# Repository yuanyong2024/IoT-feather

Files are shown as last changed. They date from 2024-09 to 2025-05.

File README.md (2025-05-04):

### This is a BG95 EVB in adafruit feather form-factor.
### It can be developed by quecpython, similar to circuit python
QQ截图20250504175747
QQ截图20250504175759

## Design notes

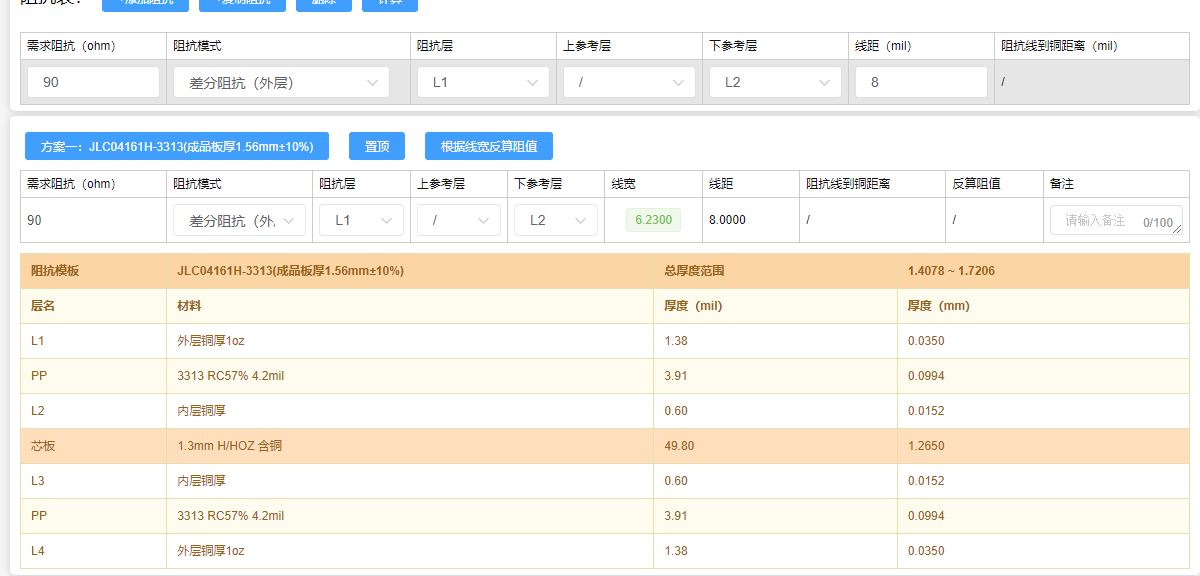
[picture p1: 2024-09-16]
hw/v0.2/90ohm_impedance_top.png

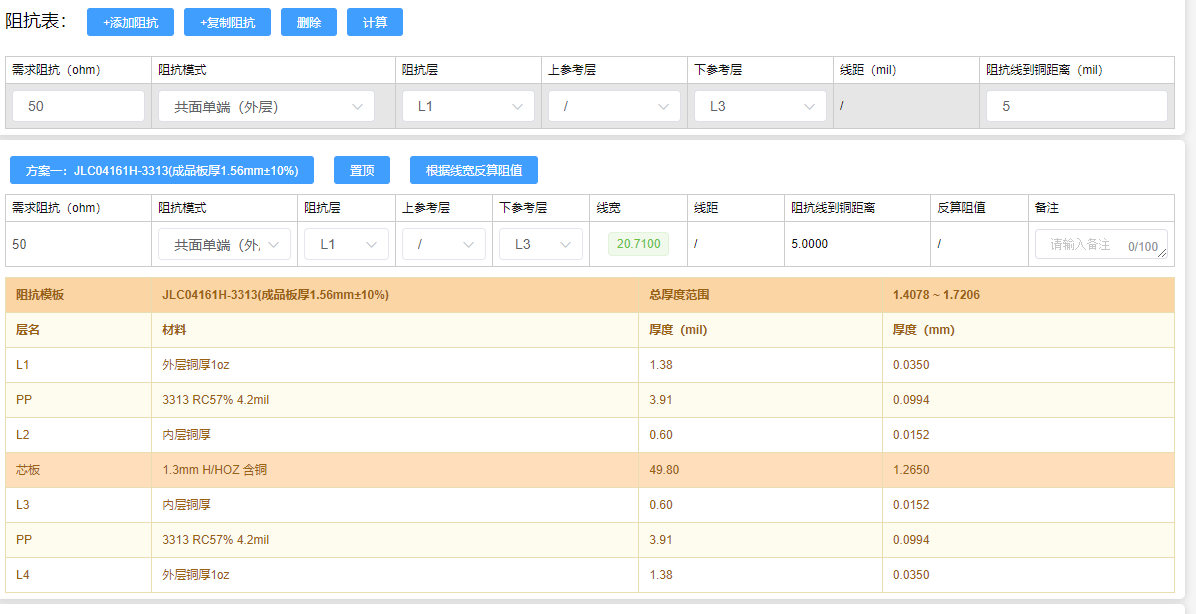
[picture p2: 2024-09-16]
hw/v0.2/50ohm_impedance.png

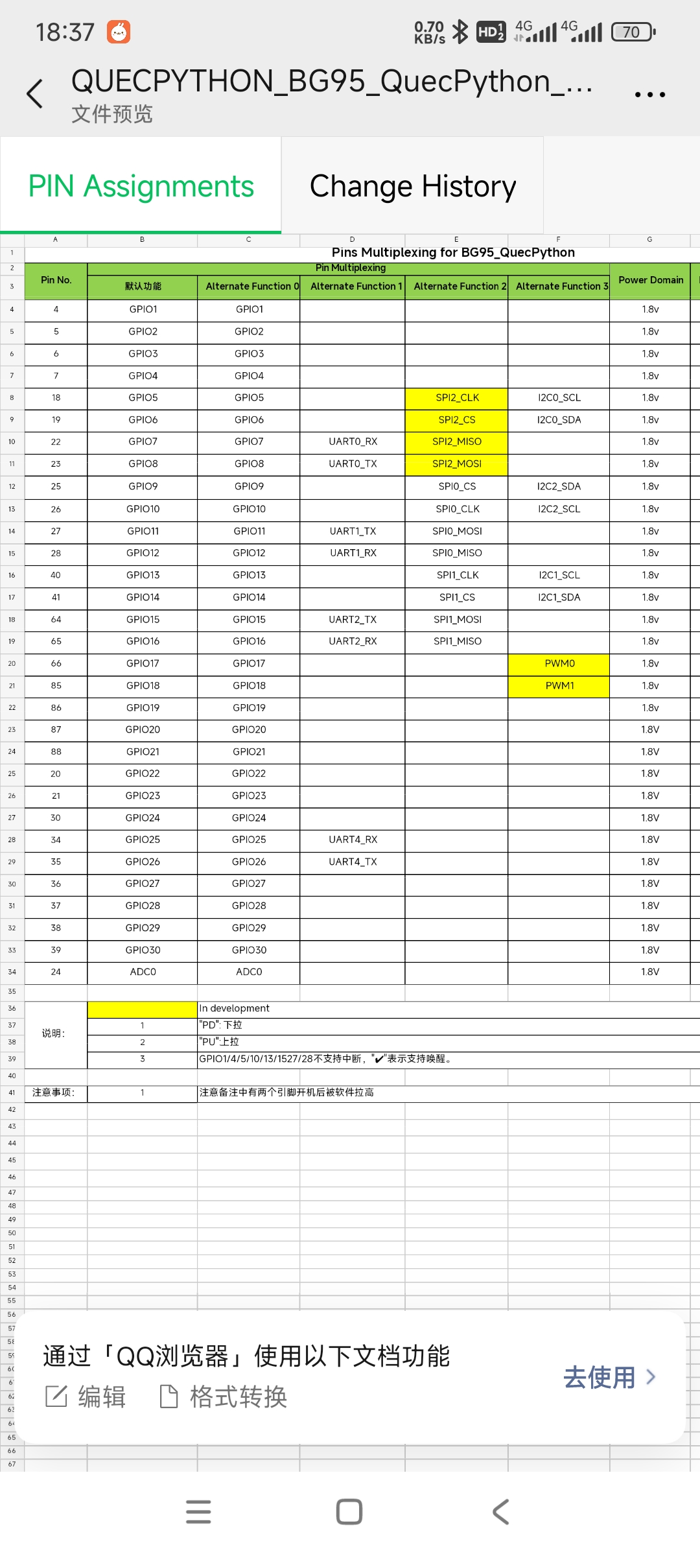
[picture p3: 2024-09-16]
reference docs/official pin map.jpg

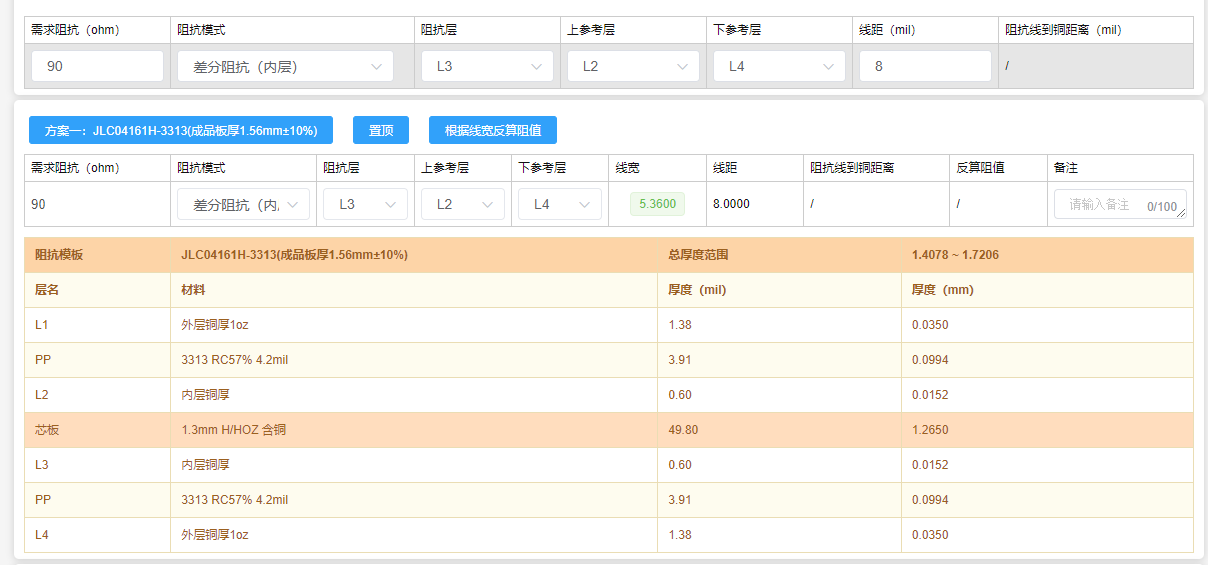
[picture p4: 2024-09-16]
hw/v0.2/90ohm_impedance.png

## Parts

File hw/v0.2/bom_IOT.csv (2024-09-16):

Ref | Qnty | Value | Footprint | PN
AE3, AE4 | 2 | Antenna_Shield | Connector_Coaxial:U.FL_Hirose_U.FL-R-SMT-1_Vertical
C1, C2, C3, C6, C11 | 5 | 33pF | Capacitor_SMD:C_0402_1005Metric | CC0402JRNPO9BN330 | 100
C4, C8, C13, C15, C18, C24, C27, C29, C30, C31, C32, C33, C34, C35, C36, C37, C38, C39, C40 | 19 | 0.1uF | Capacitor_SMD:C_0402_1005Metric | 0402F104M500NT | 500
C5, C10 | 2 | 10pF | Capacitor_SMD:C_0402_1005Metric | GRM1555C1H100JA01D | 100
C7, C12 | 2 | 100pF | Capacitor_SMD:C_0402_1005Metric | 0402CG101J500NT | 100
C9, C14, C16, C17 | 4 | 220uF | Capacitor_Tantalum_SMD:CP_EIA-3528-12_Kemet-T
C19, C23 | 2 | 0.1uF | Capacitor_SMD:C_0603_1608Metric | CC06033KRXX7RBB104 | 100
C20, C21, C22, C41 | 4 | 22uF | Capacitor_SMD:C_0603_1608Metric | CL10A226MQ8NRNC | 100
C25, C26 | 2 | 22uF | Capacitor_SMD:C_0402_1005Metric | GRM155R60J226ME11D | 10
C28 | 1 | 470nF | Capacitor_SMD:C_0402_1005Metric | CL05A474KP5NNNC | 100
C44, C47 | 2 | NC | Capacitor_SMD:C_0201_0603Metric
C45 | 1 | 100pF | Capacitor_SMD:C_0201_0603Metric | GRM0335C1H101JA01D | 100
C46 | 1 | 33pF | Capacitor_SMD:C_0201_0603Metric | GRM0335C1H330JA01D | 100
D1, D2, D3 | 3 | ESD | Diode_SMD:D_SOD-923 | ESD9B3.3ST5G | 8
D4 | 1 | PMEG6020ER | Diode_SMD:D_SOD-123 | PMEG6020ER,115 | 5
D5, D6 | 2 | LED | LED_SMD:LED_0603_1608Metric
D7 | 1 | B520S-30 | Diode_SMD:D_SOD-523 | RB520S-30 | 50
F1 | 1 | 500mA | Fuse:Fuse_0603_1608Metric | MF-FSMF050X-2 | 20
F2 | 1 | 15mA | Fuse:Fuse_0402_1005Metric | PRG15BC330MM1RC | 5
F3 | 1 | 400mA | Fuse:Fuse_0603_1608Metric | 0603L040/24AR | 5
F4 | 1 | 38mA | Fuse:Fuse_0402_1005Metric | PRG15BC330MM1RC | 3
FB1, FB2 | 2 | ~ | Inductor_SMD:L_0603_1608Metric | YI160808U300-5R0T | 50
FB3 | 1 | FerriteBead | Inductor_SMD:L_0402_1005Metric | BLM15PD121SN1D | 100
J1 | 1 | USB_C_Receptacle_USB2.0 | Connector_USB:USB_C_Receptacle_HRO_TYPE-C-31-M-12
J2 | 1 | Feather Interface | Connector_PinHeader_2.54mm:PinHeader_1x12_P2.54mm_Vertical_SMD_Pin1Left
J3 | 1 | Feather Interface | Connector_PinHeader_2.54mm:PinHeader_1x16_P2.54mm_Vertical_SMD_Pin1Right
J4 | 1 | JAE_SIM_Card_SF72S006 | Connector_JAE:JAE_SIM_Card_SF72S006
J5 | 1 | S2B-PH-SM4-TB_LF__SN_ | myfootprintlib:JST_S2B-PH-SM4-TB_LF__SN_
L1 | 1 | 1uH | Inductor_SMD:L_Bourns-SRN4018 | YSMC0420V-1R0M | 1
L3 | 1 | 47nH | Inductor_SMD:L_0402_1005Metric | LQG15HS47NJ02D | 100
Q1 | 1 | AO3401A | Package_TO_SOT_SMD:SOT-23 | AO3401A | 10
Q2, Q3 | 2 | BSS138 | Package_TO_SOT_SMD:SOT-523
R1, R2 | 2 | 22R | Resistor_SMD:R_0402_1005Metric | 00402WGF220JTCE | 100
R3, R4 | 2 | 5.1K | Resistor_SMD:R_0402_1005Metric | 0402WGF5101TCE | 100
R5 | 1 | 1.2M 1% | Resistor_SMD:R_0402_1005Metric | 0402WGF1204TCE | 100
R6 | 1 | 182K 1% | Resistor_SMD:R_0402_1005Metric | 0402WGF1823TCE | 100
R7 | 1 | 51K | Resistor_SMD:R_0402_1005Metric | 0402WGF5102TCE | 100
R8 | 1 | 15K | Resistor_SMD:R_0402_1005Metric | 0402WGF1502TCE | 100
R9, R15, R16, R18 | 4 | 100K | Resistor_SMD:R_0402_1005Metric | RC-02W1003FT | 100
R10 | 1 | 0R | Resistor_SMD:R_0201_0603Metric | RC0201JR-070RL | 1000
R11 | 1 | DNP | Resistor_SMD:R_0402_1005Metric
R12 | 1 | 243K | Resistor_SMD:R_0402_1005Metric | FRC0402F2433TS | 100
R13 | 1 | 24.3K | Resistor_SMD:R_0402_1005Metric | 0402WGF2432TCE | 100
R14 | 1 | 200K | Resistor_SMD:R_0402_1005Metric | 0402WGF2003TCE | 100
R17 | 1 | 10K | Resistor_SMD:R_0402_1005Metric | 0402WGF1002TCE | 1000
R19, R20 | 2 | 1K | Resistor_SMD:R_0402_1005Metric | RC-02W102JT | 100
SW1 | 1 | SW_Omron_B3FS | Button_Switch_SMD:SW_Push_SPST_NO_Alps_SKRK
TP2, TP4, TP5, TP6, TP7, TP8 | 6 | TestPoint | TestPoint:TestPoint_Pad_D1.0mm
U1 | 1 | BG95M3LA-64-SGNS | myfootprintlib:XCVR_BG95M3LA-64-SGNS
U2 | 1 | TPS63020DSJR | myfootprintlib:IC_TPS63020DSJR | TPS63020DSJR | 1
U3, U4, U5, U6, U10 | 5 | TXS0104EYZTR | myfootprintlib:BGA12N50P4X3_186X136X62N | TXS0104EYZTR | 5
U7 | 1 | RS2299XTQC16 | Package_DFN_QFN:QFN-16-1EP_3x3mm_P0.5mm_EP1.75x1.75mm | RS2299XTQC16 | 1
U8 | 1 | XC6119C32A7R-G | kiCadPcbLib:USPN-4 | XC6119C32A7R-G
U12 | 1 | D3V3XA4B10LP | Package_DFN_QFN:Diodes_UDFN-10_1.0x2.5mm_P0.5mm | D3V3XA4B10LP-7 | 9
U13 | 1 | TLV75533PDRV | Package_SON:WSON-6-1EP_2x2mm_P0.65mm_EP1x1.6mm | TLV75533PDRV | 5
U14 | 1 | RT9526AGQW | Package_DFN_QFN:DFN-8-1EP_3x2mm_P0.5mm_EP1.7x1.4mm
U15 | 1 | CM1103 | myfootprintlib:CM1103-QFNTA | CM1103-QFNTA | 1

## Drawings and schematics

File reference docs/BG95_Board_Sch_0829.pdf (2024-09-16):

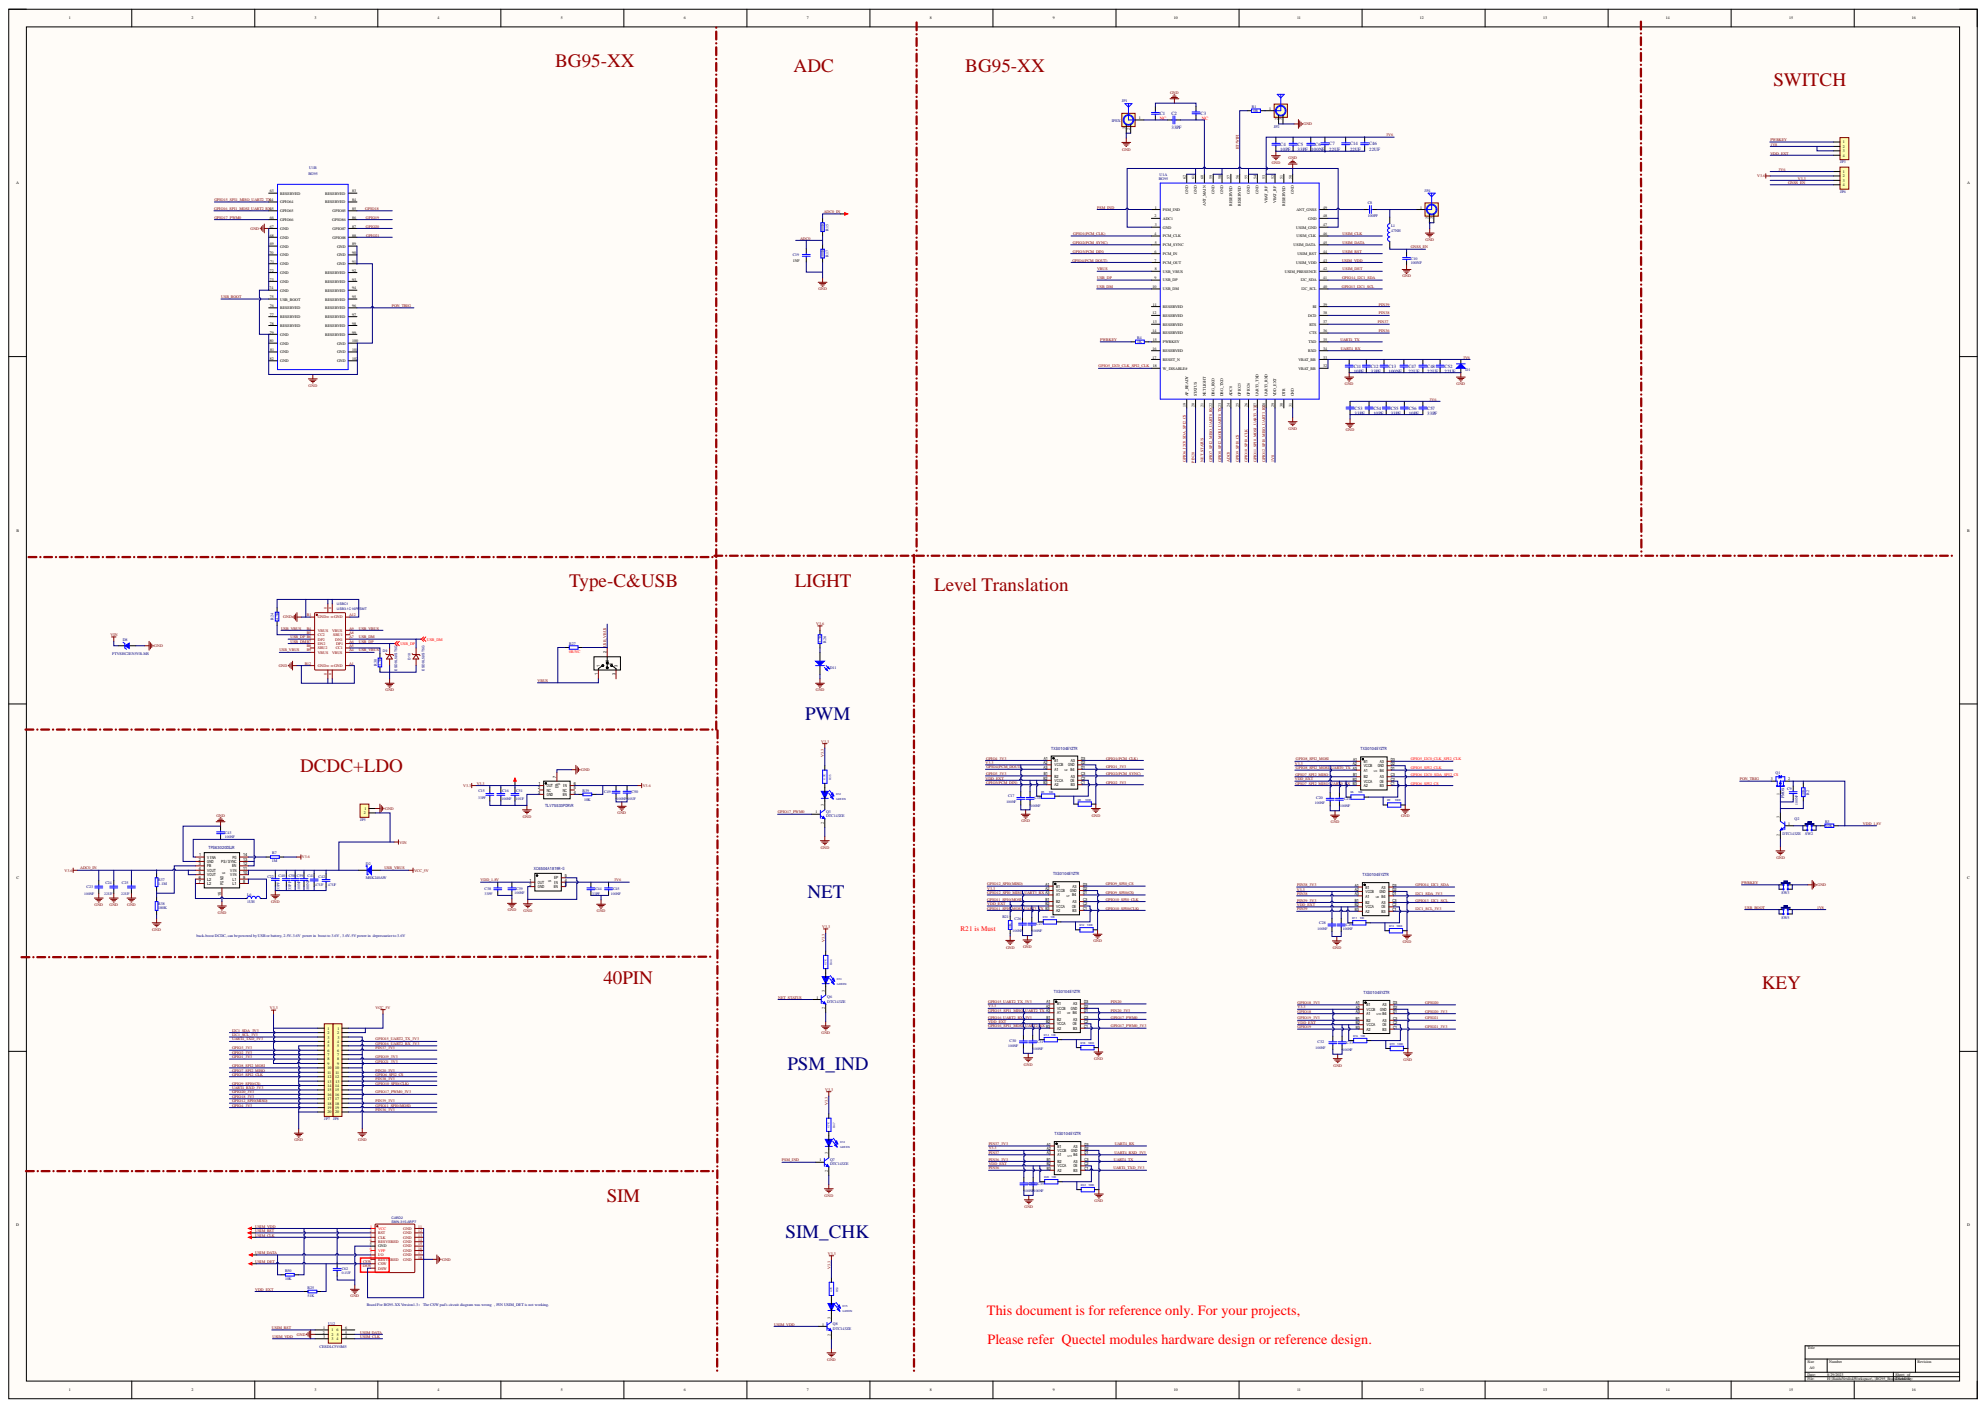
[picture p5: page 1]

T | C62 0.1UF | 8 C S W C RE S W SVE DS W DSW

This document is for reference only. For your projects,

Please refer Quectel modules hardware design or reference design.

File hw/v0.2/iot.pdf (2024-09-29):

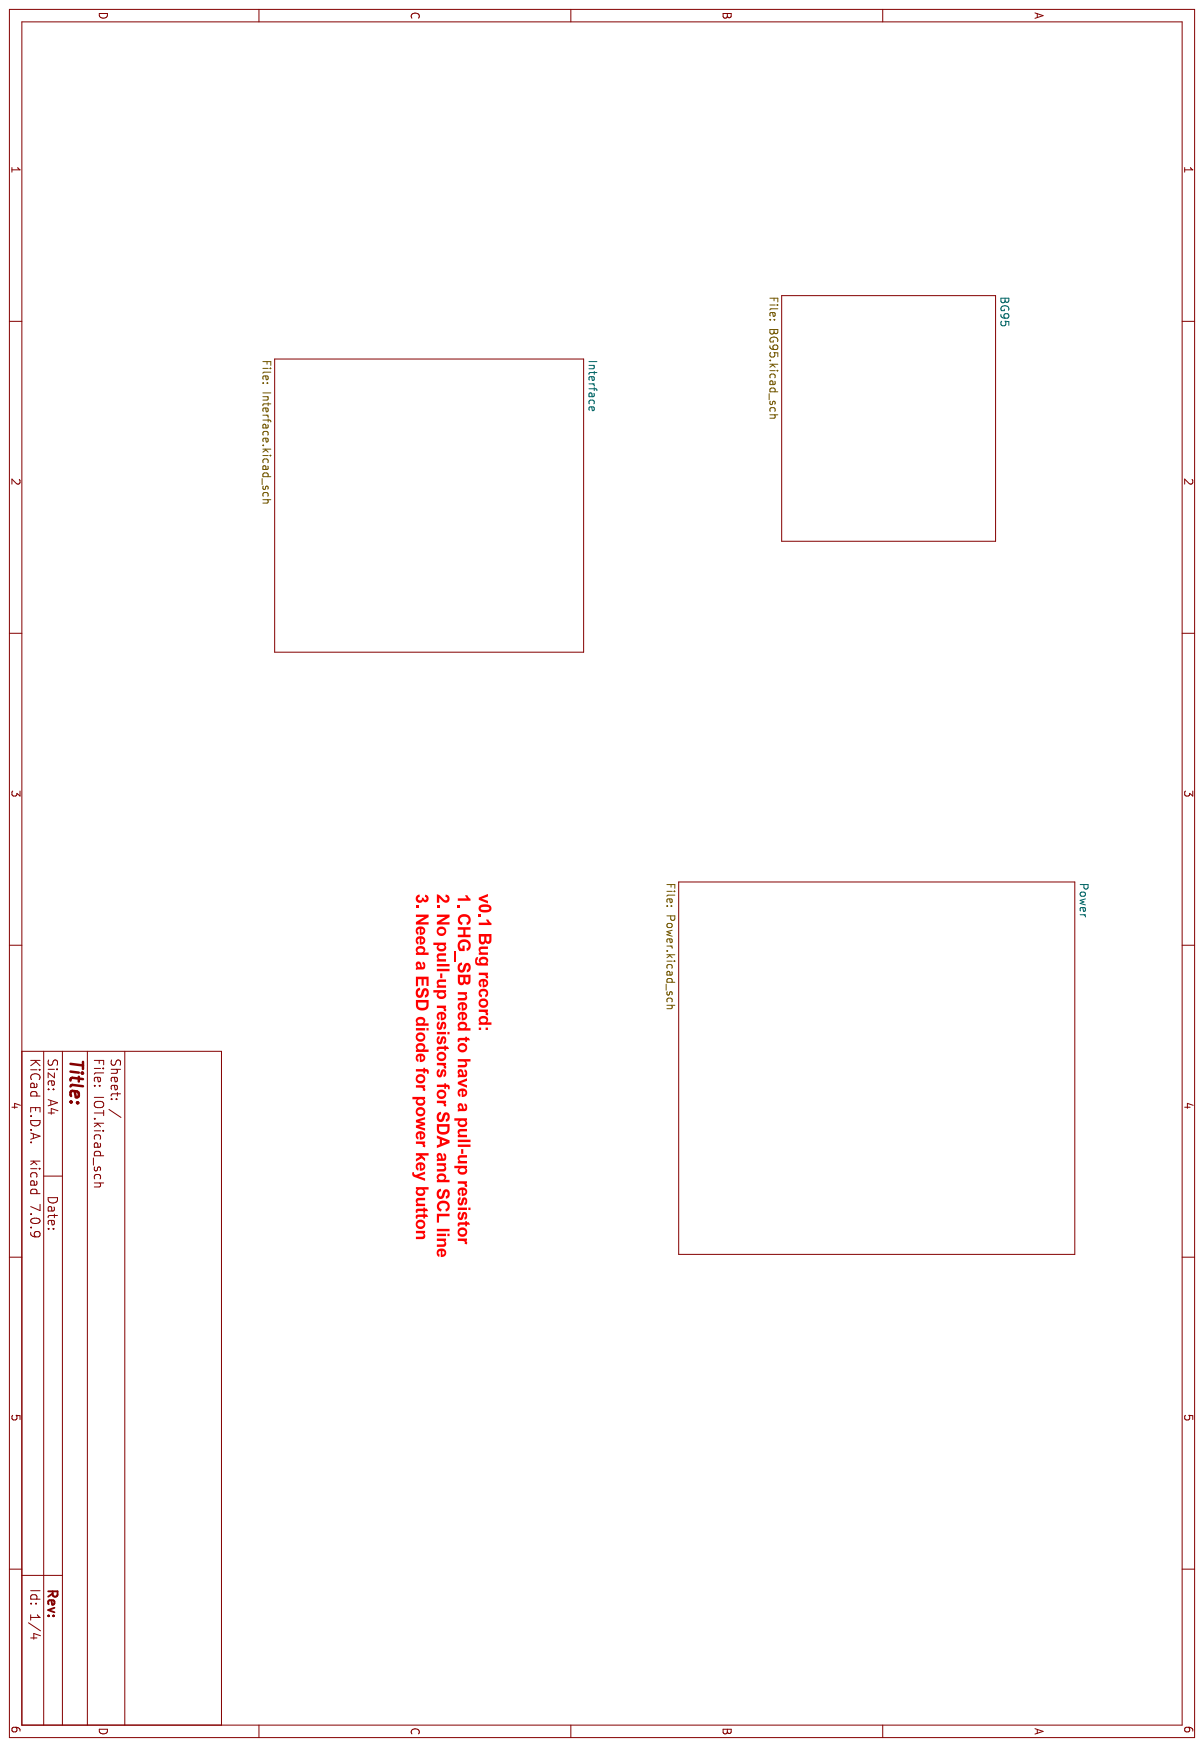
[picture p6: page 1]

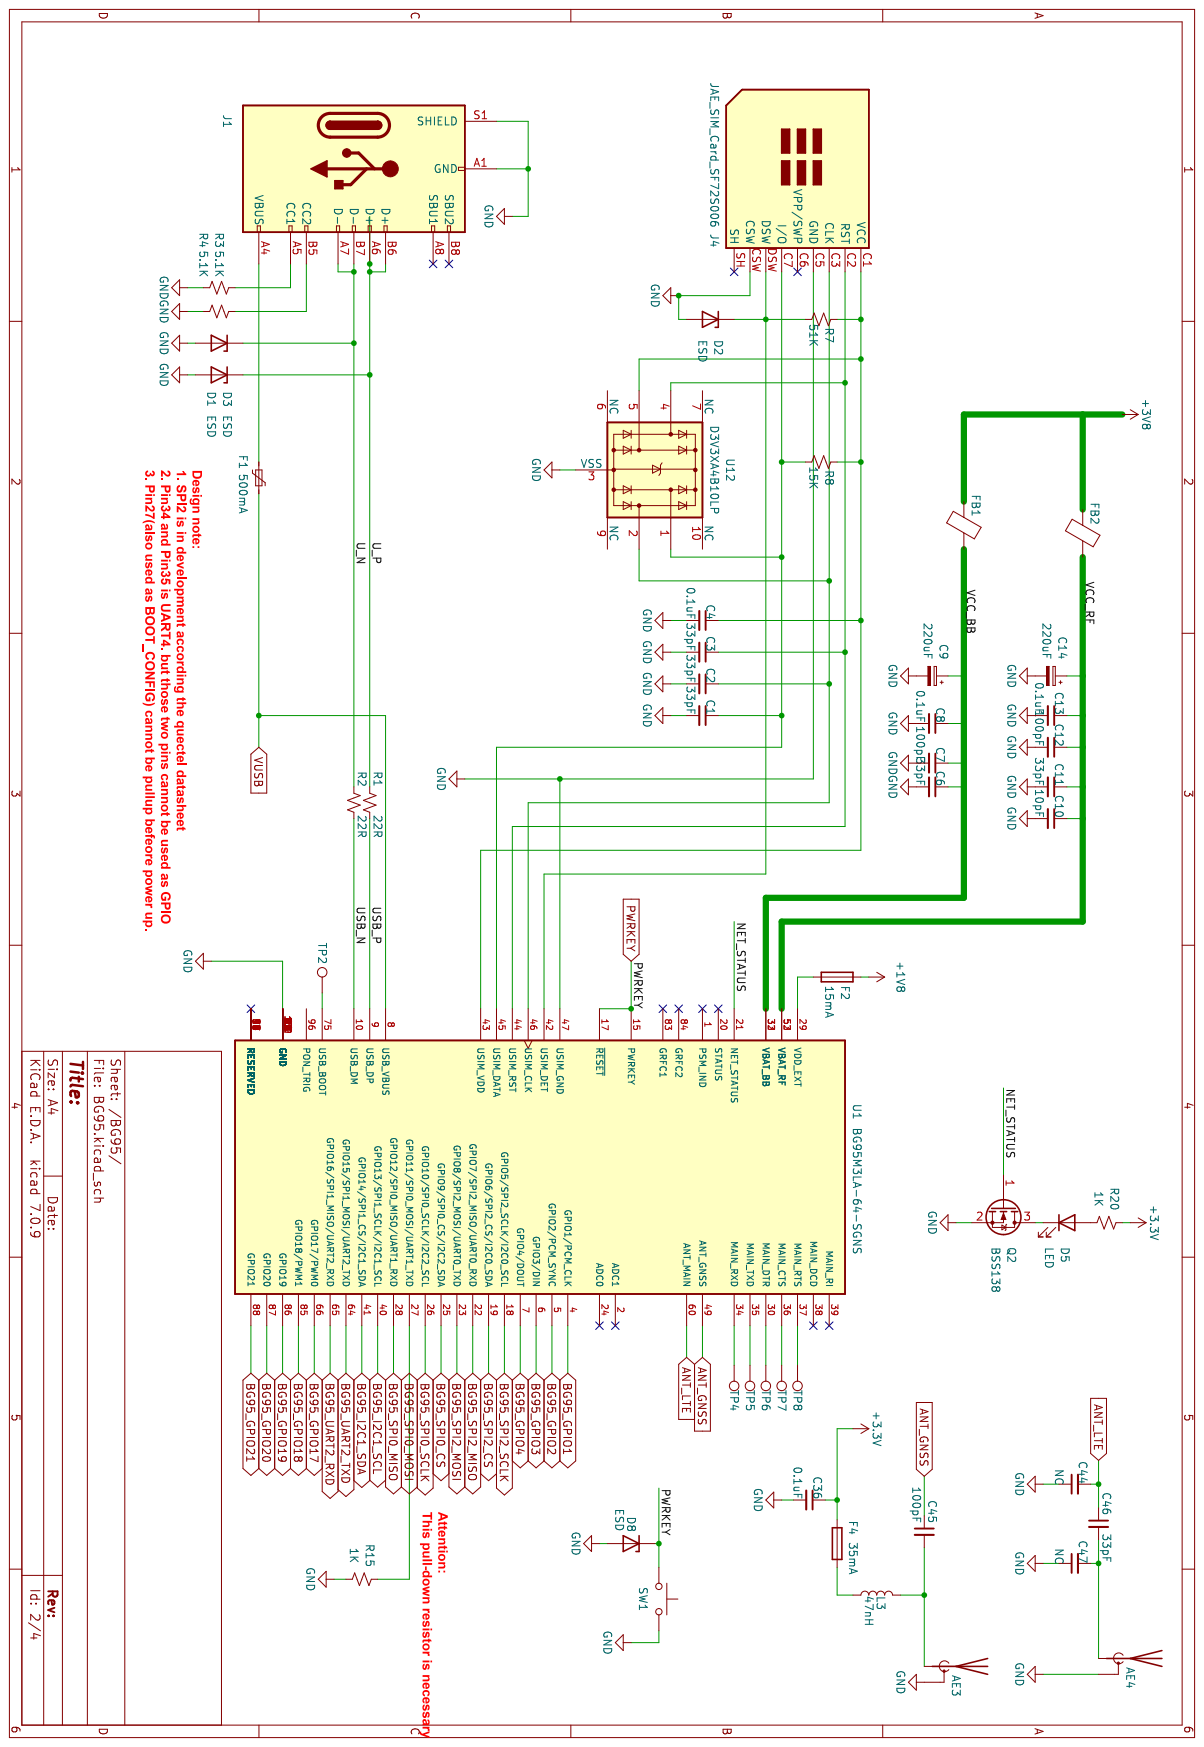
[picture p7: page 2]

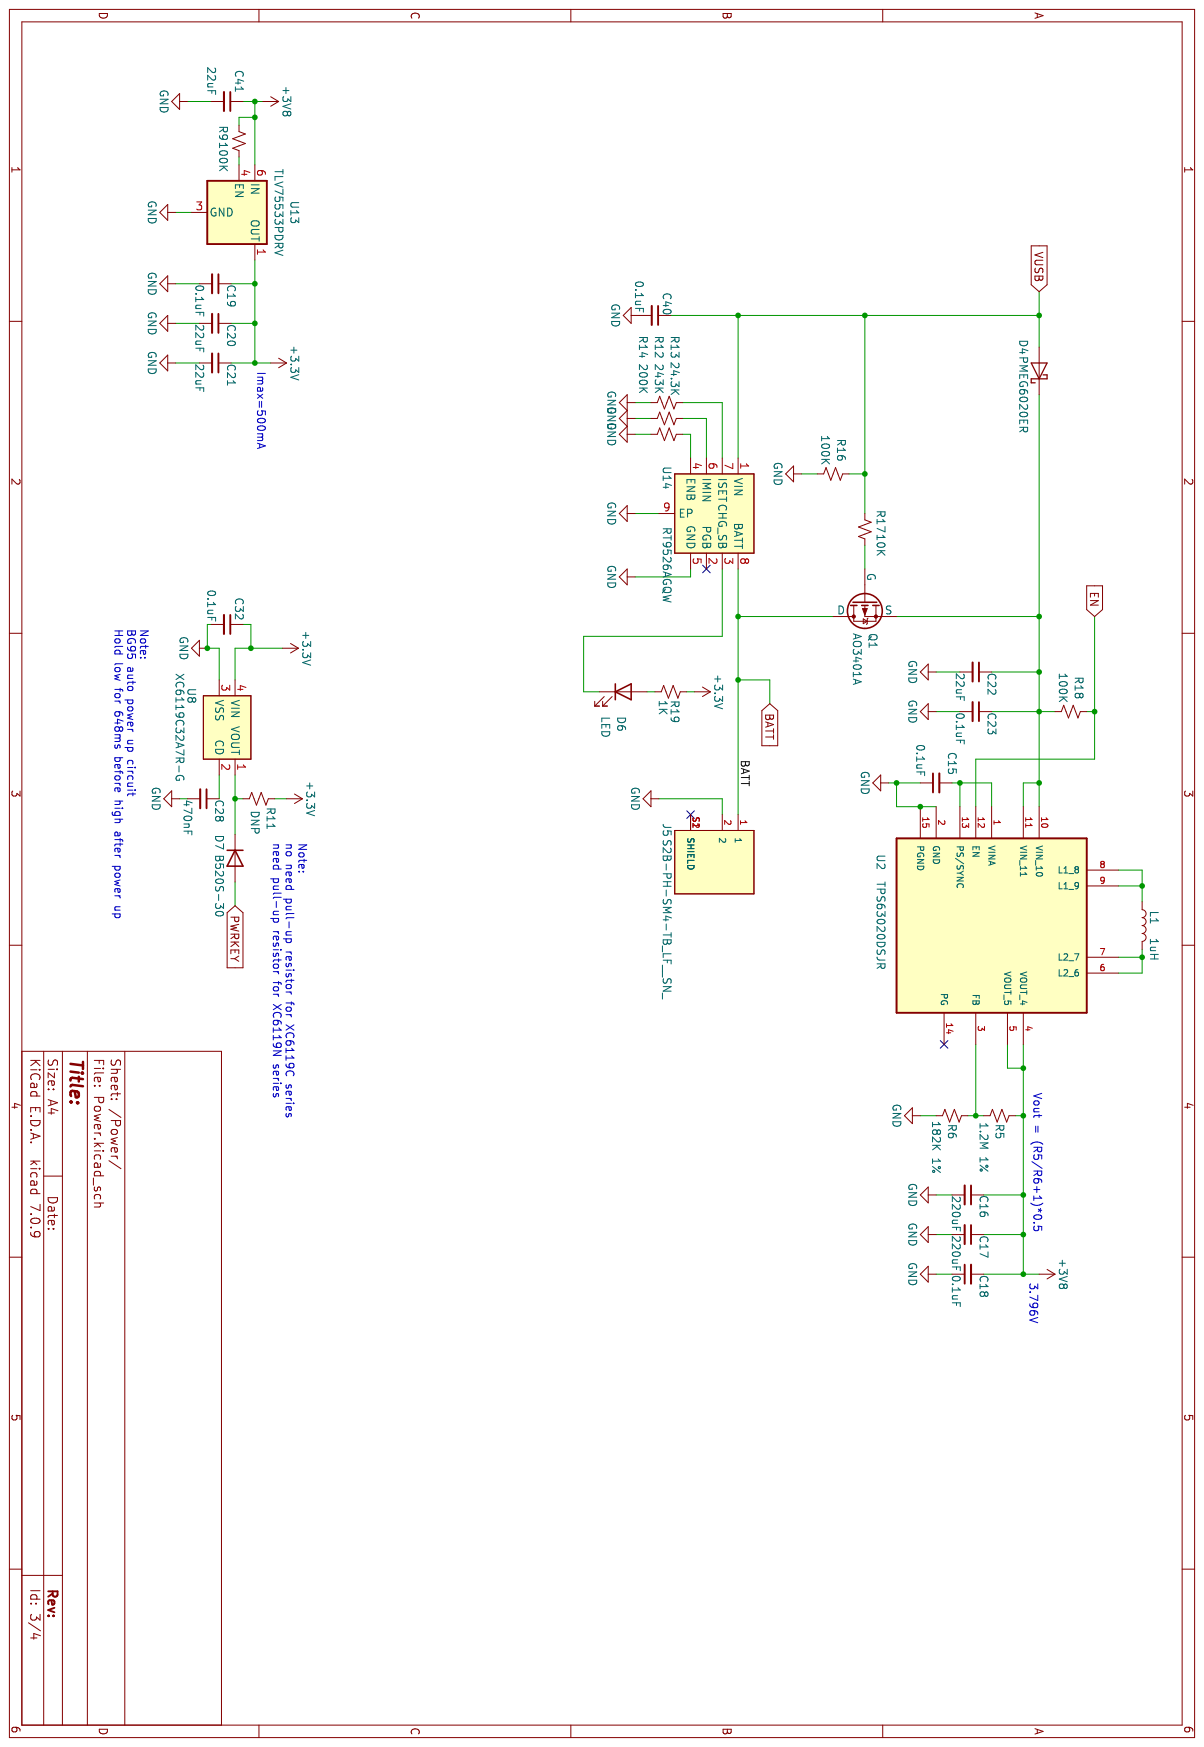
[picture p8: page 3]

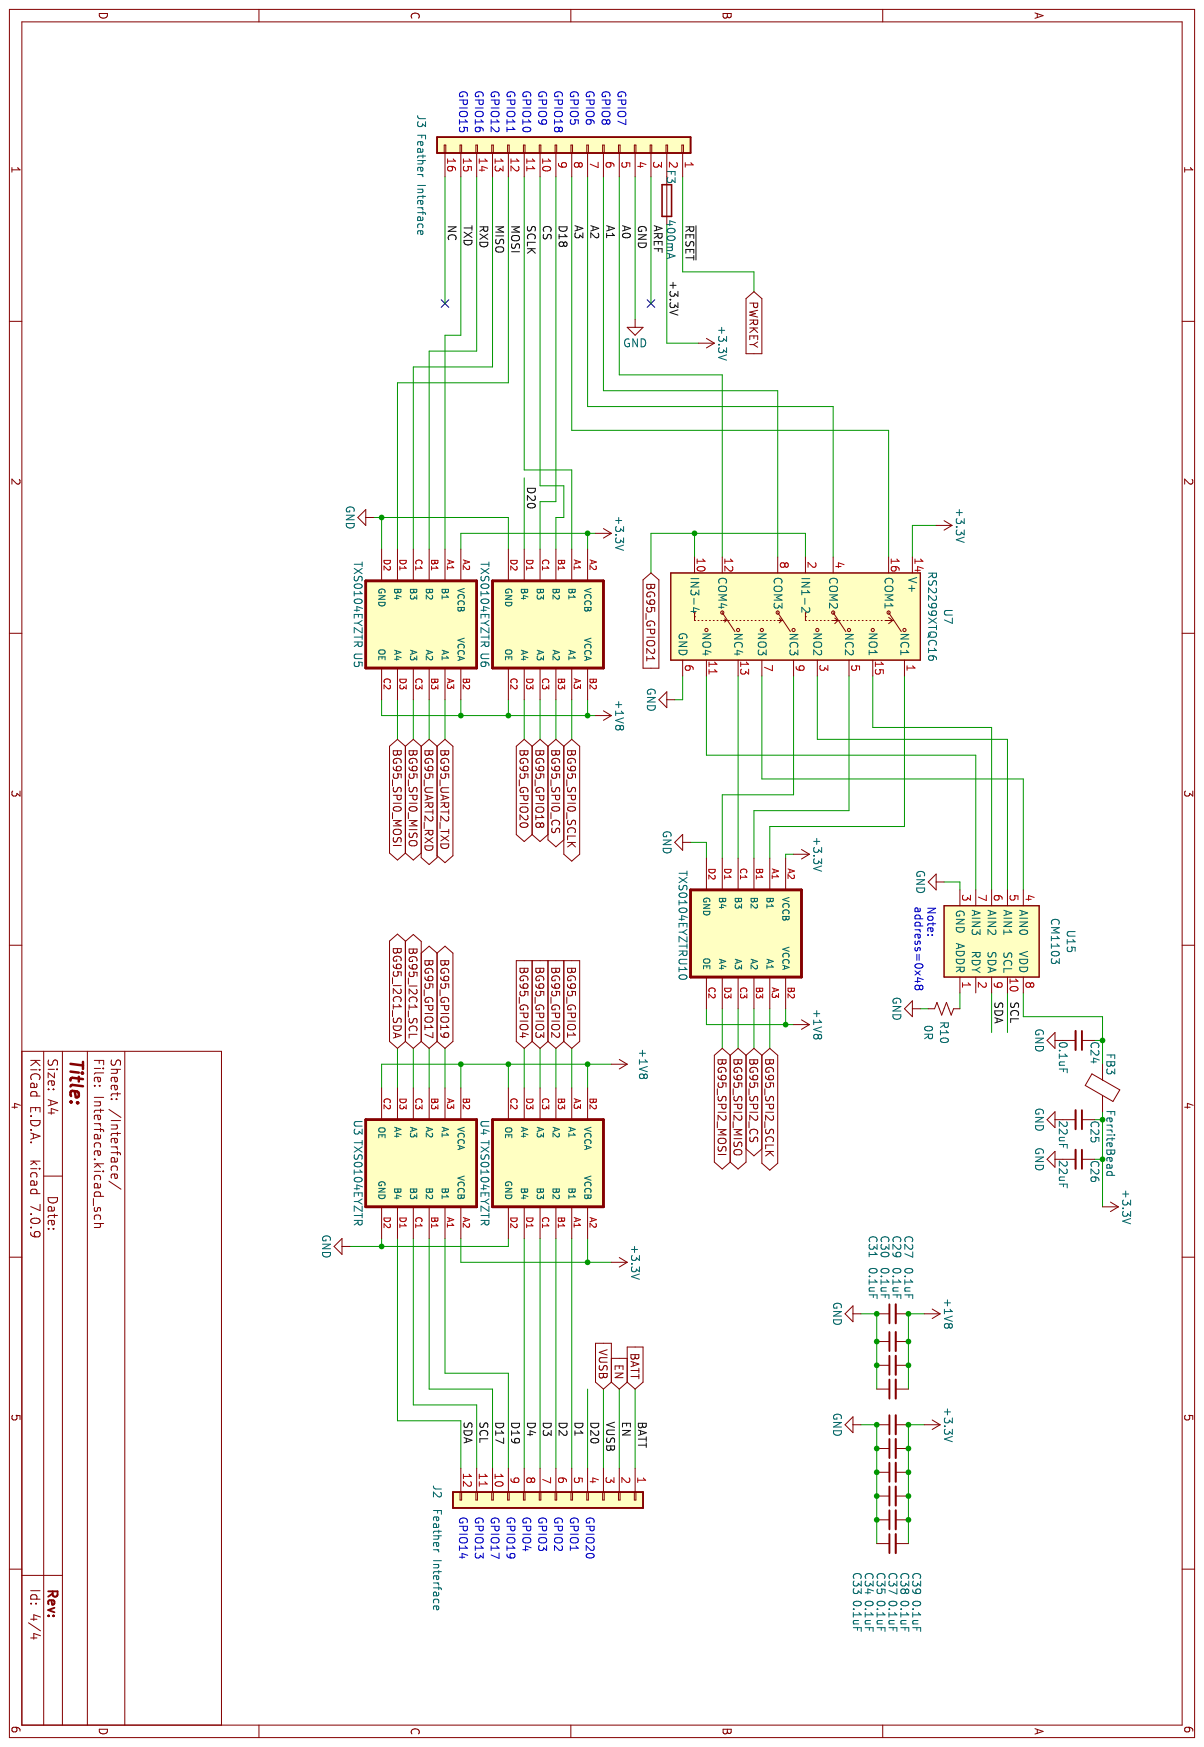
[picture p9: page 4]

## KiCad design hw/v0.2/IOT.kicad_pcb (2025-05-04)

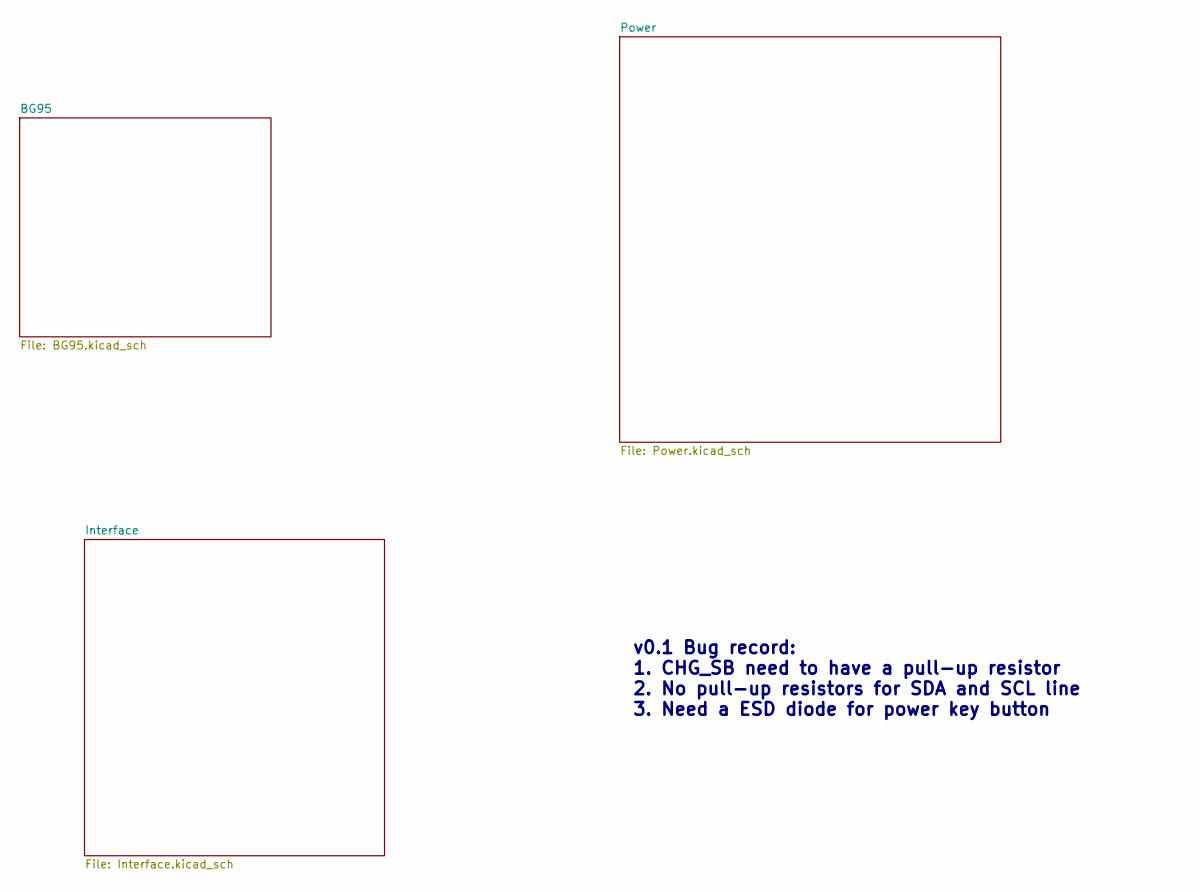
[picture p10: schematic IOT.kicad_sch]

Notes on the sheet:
v0.1 Bug record: 1. CHG_SB need to have a pull-up resistor 2. No pull-up resistors for SDA and SCL line 3. Need a ESD diode for power key button

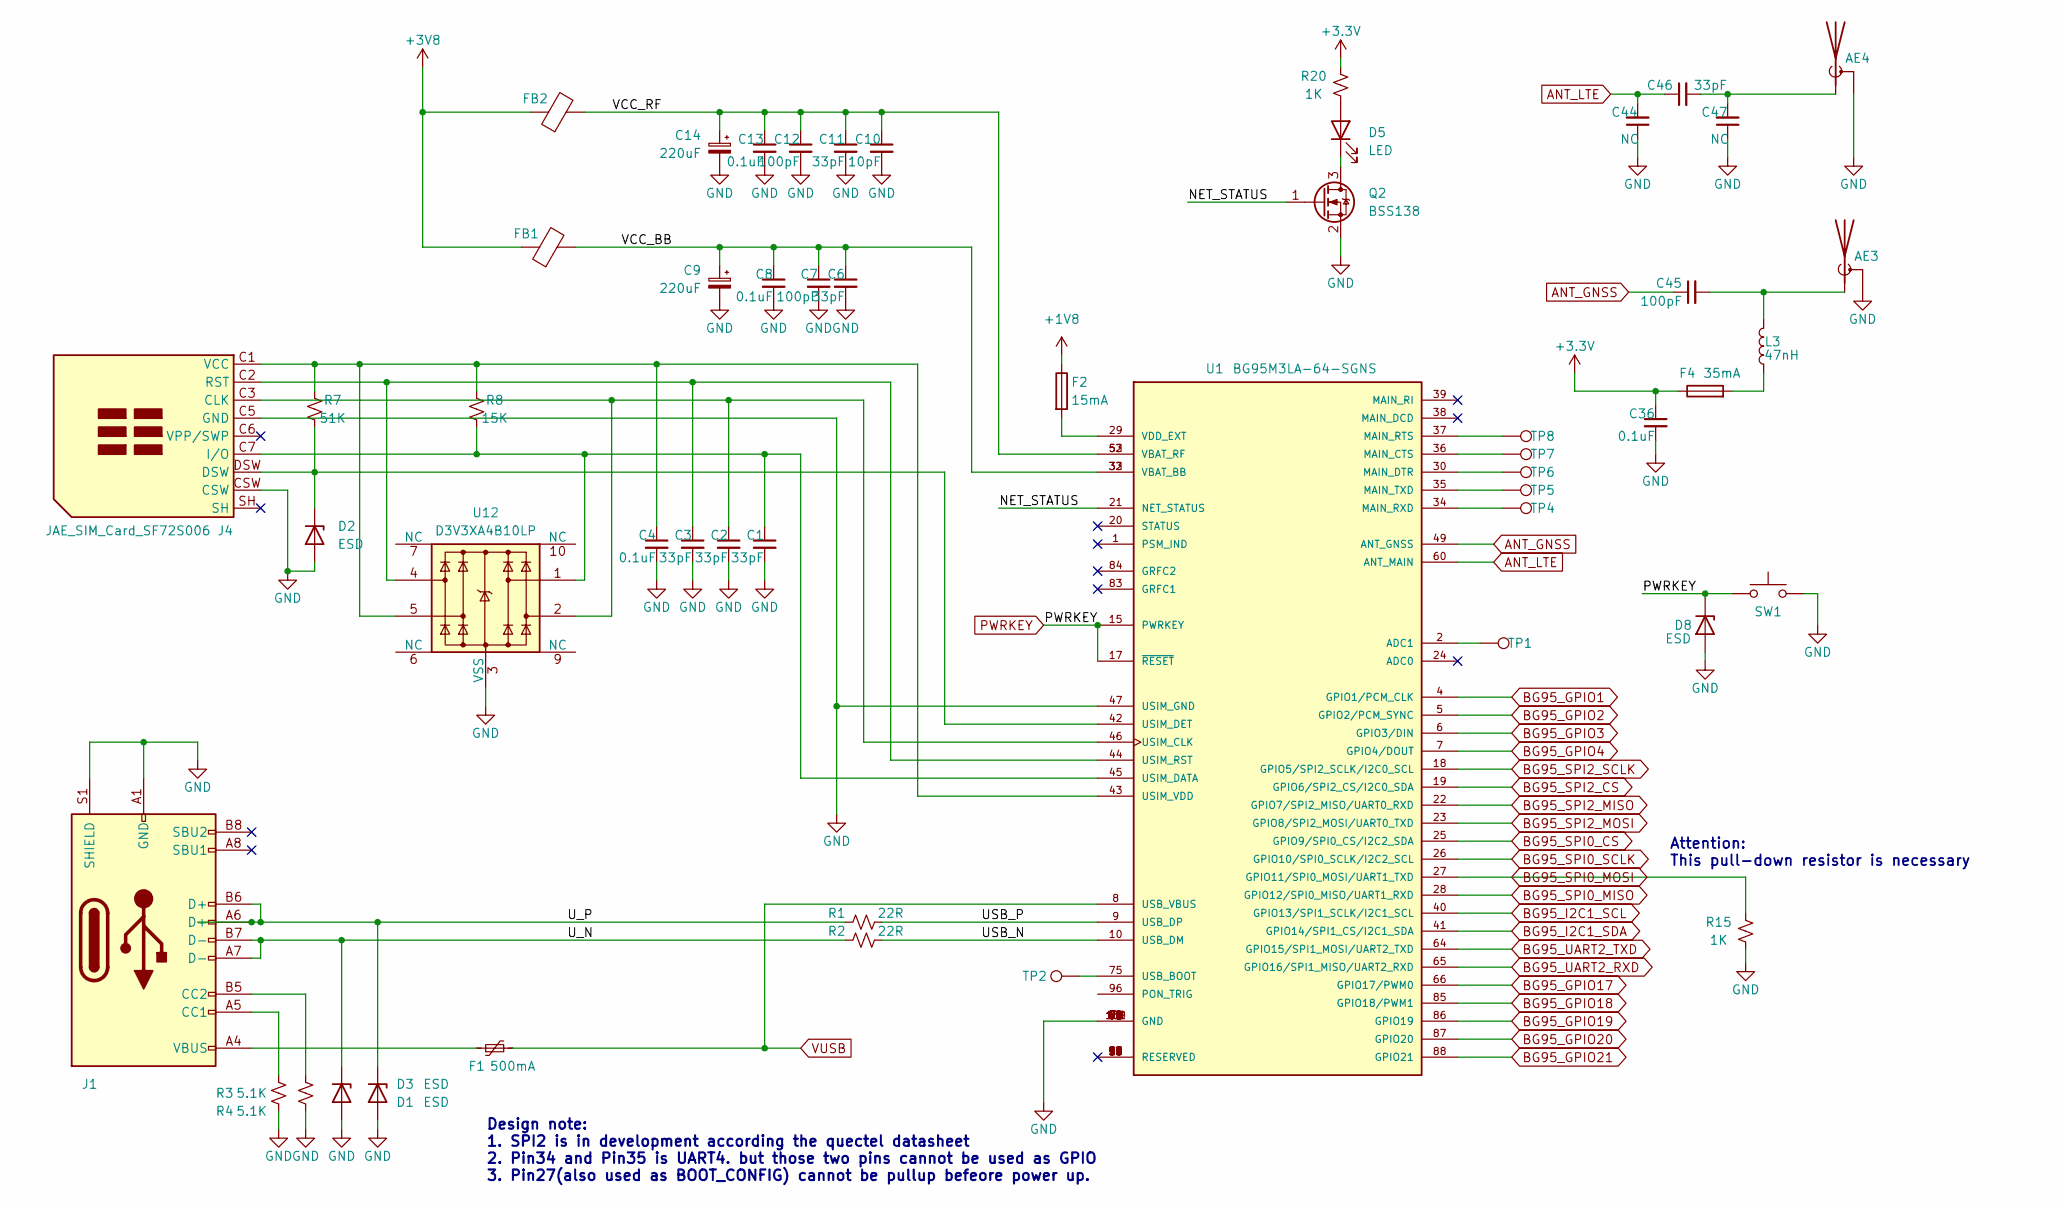
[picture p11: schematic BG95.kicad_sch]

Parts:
AE3, AE4: Antenna_Shield; U.FL_Hirose_U.FL-R-SMT-1_Vertical
C1, C2, C3, C6, C11: 33pF; C_0402_1005Metric
C4, C8, C13, C36: 0.1uF; C_0402_1005Metric
C7, C12: 100pF; C_0402_1005Metric
C9, C14: 220uF; CP_EIA-3528-12_Kemet-T
C10: 10pF; C_0402_1005Metric
C44, C47: NC; C_0201_0603Metric
C45: 100pF; C_0201_0603Metric
C46: 33pF; C_0201_0603Metric
D1, D2, D3: ESD; D_SOD-923
D5: LED; LED_0603_1608Metric
D8: ESD; D_SOD-523
F1: 500mA; Fuse_0603_1608Metric
F2: 15mA; Fuse_0402_1005Metric
F4: 35mA; Fuse_0402_1005Metric
FB1, FB2: L_0603_1608Metric
J1: USB_C_Receptacle_USB2.0; USB_C_Receptacle_HRO_TYPE-C-31-M-12
J4: JAE_SIM_Card_SF72S006
L3: 47nH; L_0402_1005Metric
Q2: BSS138; SOT-523
R1, R2: 22R; R_0402_1005Metric
R3, R4: 5.1K; R_0402_1005Metric
R7: 51K; R_0402_1005Metric
R8: 15K; R_0402_1005Metric
R15, R20: 1K; R_0402_1005Metric
SW1: SW_Omron_B3FS; SW_Push_SPST_NO_Alps_SKRK
TP1, TP2, TP4, TP5, TP6, TP7, TP8: TestPoint; TestPoint_Pad_D1.0mm
U1: BG95M3LA-64-SGNS; XCVR_BG95M3LA-64-SGNS
U12: D3V3XA4B10LP; Diodes_UDFN-10_1.0x2.5mm_P0.5mm

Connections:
+1V8: F2.1; also elsewhere on the board
+3V8: FB1.1, FB2.1; also elsewhere on the board
/BG95/NET_STATUS: Q2.1 (G), U1.21 (NET_STATUS)
/BG95/USB_N: R2.2, U1.10 (USB_DM)
/BG95/USB_P: R1.2, U1.9 (USB_DP)
/BG95/U_N: D1.1 (K), J1.A7 (D-), J1.B7 (D-), R2.1
/BG95/U_P: D3.1 (K), J1.A6 (D+), J1.B6 (D+), R1.1
/BG95/VCC_BB: C6.1, C7.1, C8.1, C9.1, FB1.2, U1.32 (VBAT_BB), U1.33 (VBAT_BB)
/BG95/VCC_RF: C10.1, C11.1, C12.1, C13.1, C14.1, FB2.2, U1.52 (VBAT_RF), U1.53 (VBAT_RF)
ANT_GNSS: C45.1, U1.49 (ANT_GNSS)
ANT_LTE: C44.2, C46.1, U1.60 (ANT_MAIN)
BG95_GPIO1: U1.4 (GPIO1/PCM_CLK); also elsewhere on the board
BG95_GPIO2: U1.5 (GPIO2/PCM_SYNC); also elsewhere on the board
BG95_GPIO3: U1.6 (GPIO3/DIN); also elsewhere on the board
BG95_GPIO4: U1.7 (GPIO4/DOUT); also elsewhere on the board
BG95_GPIO17: U1.66 (GPIO17/PWM0); also elsewhere on the board
BG95_GPIO18: U1.85 (GPIO18/PWM1); also elsewhere on the board
BG95_GPIO19: U1.86 (GPIO19); also elsewhere on the board
BG95_GPIO20: U1.87 (GPIO20); also elsewhere on the board
BG95_GPIO21: U1.88 (GPIO21); also elsewhere on the board
BG95_I2C1_SCL: U1.40 (GPIO13/SPI1_SCLK/I2C1_SCL); also elsewhere on the board
BG95_I2C1_SDA: U1.41 (GPIO14/SPI1_CS/I2C1_SDA); also elsewhere on the board
BG95_SPI0_CS: U1.25 (GPIO9/SPI0_CS/I2C2_SDA); also elsewhere on the board
BG95_SPI0_MISO: U1.28 (GPIO12/SPI0_MISO/UART1_RXD); also elsewhere on the board
BG95_SPI0_MOSI: R15.1, U1.27 (GPIO11/SPI0_MOSI/UART1_TXD); also elsewhere on the board
BG95_SPI0_SCLK: U1.26 (GPIO10/SPI0_SCLK/I2C2_SCL); also elsewhere on the board
BG95_SPI2_CS: U1.19 (GPIO6/SPI2_CS/I2C0_SDA); also elsewhere on the board
BG95_SPI2_MISO: U1.22 (GPIO7/SPI2_MISO/UART0_RXD); also elsewhere on the board
BG95_SPI2_MOSI: U1.23 (GPIO8/SPI2_MOSI/UART0_TXD); also elsewhere on the board
BG95_SPI2_SCLK: U1.18 (GPIO5/SPI2_SCLK/I2C0_SCL); also elsewhere on the board
BG95_UART2_RXD: U1.65 (GPIO16/SPI1_MISO/UART2_RXD); also elsewhere on the board
BG95_UART2_TXD: U1.64 (GPIO15/SPI1_MOSI/UART2_TXD); also elsewhere on the board
GND: AE3.2 (Shield), AE4.2 (Shield), C1.2, C2.2, C3.2, C4.2, C6.2, C7.2, C8.2, C9.2, C10.2, C11.2, C12.2, C13.2, C14.2, C36.2, C44.1, C47.1, D1.2 (A), D2.2 (A), D3.2 (A), D8.2 (A), J1.A1 (GND), J1.A12 (GND), J1.B1 (GND), J1.B12 (GND), J1.S1 (SHIELD), J4.C5 (GND), J4.CSW, Q2.2 (S), R3.1, R4.1, R15.2, SW1.2, U1.3 (GND), U1.31 (GND), U1.47 (USIM_GND), U1.48 (GND), U1.50 (GND), U1.54 (GND), U1.55 (GND), U1.58 (GND), U1.59 (GND), U1.61 (GND), U1.62 (GND), U1.67 (GND), U1.68 (GND), U1.69 (GND), U1.70 (GND), U1.71 (GND), U1.72 (GND), U1.73 (GND), U1.74 (GND), U1.79 (GND), U1.80 (GND), U1.81 (GND), U1.82 (GND), U1.89 (GND), U1.90 (GND), U1.91 (GND), U1.100 (GND), U1.101 (GND), U1.102 (GND), U12.3 (VSS), U12.8 (VSS); also elsewhere on the board
unnamed: AE3.1 (A), C45.2, L3.1
unnamed: AE4.1 (A), C46.2, C47.2
unnamed: D2.1 (K), J4.DSW, R7.1, U1.42 (USIM_DET)
unnamed: D5.2 (A), R20.2
unnamed: D5.1 (K), Q2.3 (D)
unnamed: F1.1, J1.A4 (VBUS), J1.A9 (VBUS), J1.B4 (VBUS), J1.B9 (VBUS)
unnamed: J1.A5 (CC1), R3.2
unnamed: J1.B5 (CC2), R4.2
unnamed: C2.1, J4.C3 (CLK), U1.46 (USIM_CLK), U12.2
unnamed: C1.1, J4.C7 (I/O), R8.1, U1.45 (USIM_DATA), U12.1
unnamed: C3.1, J4.C2 (RST), U1.44 (USIM_RST), U12.4
unnamed: C4.1, J4.C1 (VCC), R7.2, R8.2, U1.43 (USIM_VDD), U12.5
unnamed: TP1.1, U1.2 (ADC1)
unnamed: TP7.1, U1.36 (MAIN_CTS)
unnamed: TP6.1, U1.30 (MAIN_DTR)
unnamed: TP8.1, U1.37 (MAIN_RTS)
unnamed: TP4.1, U1.34 (MAIN_RXD)
unnamed: TP5.1, U1.35 (MAIN_TXD)
unnamed: TP2.1, U1.75 (USB_BOOT)
unnamed: F2.2, U1.29 (VDD_EXT)
PWRKEY: D8.1 (K), SW1.1, U1.15 (PWRKEY), U1.17 (~RESET); also elsewhere on the board
VUSB: F1.2, U1.8 (USB_VBUS); also elsewhere on the board

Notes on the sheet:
Attention: This pull-down resistor is necessary
Design note: 1. SPI2 is in development according the quectel datasheet 2. Pin34 and Pin35 is UART4. but those two pins cannot be used as GPIO 3. Pin27(also used as BOOT_CONFIG) cannot be pullup befeore power up.

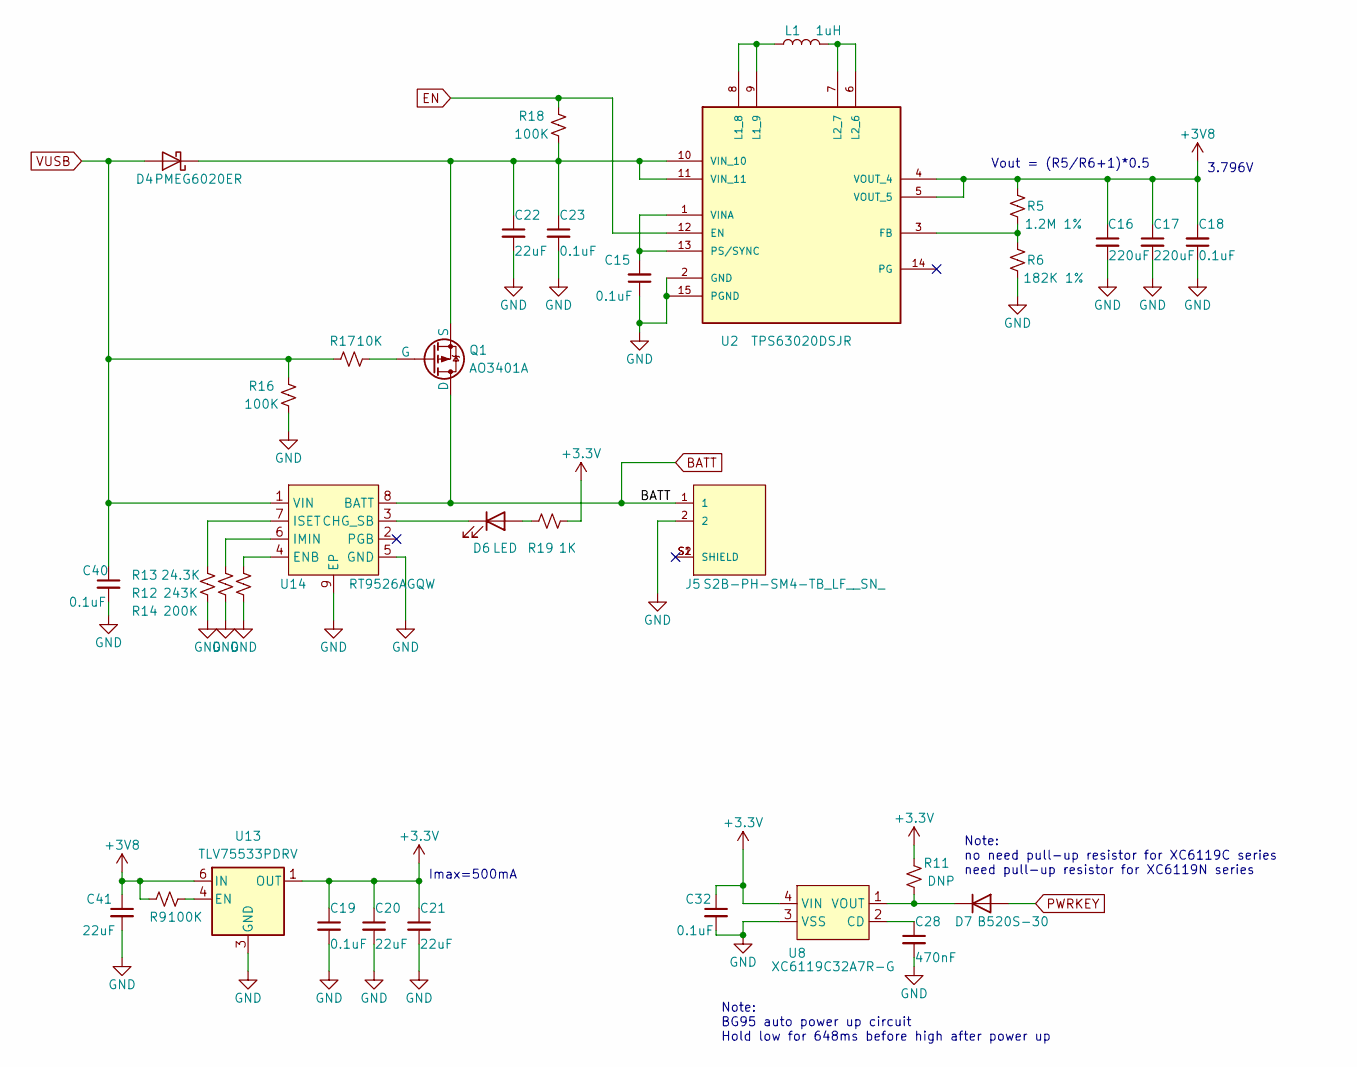
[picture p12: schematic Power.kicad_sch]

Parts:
C15, C18, C32, C40: 0.1uF; C_0402_1005Metric
C16, C17: 220uF; CP_EIA-3528-12_Kemet-T
C19, C23: 0.1uF; C_0603_1608Metric
C20, C21, C22, C41: 22uF; C_0603_1608Metric
C28: 470nF; C_0402_1005Metric
D4: PMEG6020ER; D_SOD-123
D6: LED; LED_0603_1608Metric
D7: B520S-30; D_SOD-523
J5: S2B-PH-SM4-TB_LF__SN_; JST_S2B-PH-SM4-TB_LF__SN_
L1: 1uH; L_Bourns-SRN4018
Q1: AO3401A; SOT-23
R5: 1.2M 1%; R_0402_1005Metric
R6: 182K 1%; R_0402_1005Metric
R9, R16, R18: 100K; R_0402_1005Metric
R11: DNP; R_0402_1005Metric
R12: 243K; R_0402_1005Metric
R13: 24.3K; R_0402_1005Metric
R14: 200K; R_0402_1005Metric
R17: 10K; R_0402_1005Metric
R19: 1K; R_0402_1005Metric
U2: TPS63020DSJR; IC_TPS63020DSJR
U8: XC6119C32A7R-G; USPN-4
U13: TLV75533PDRV; WSON-6-1EP_2x2mm_P0.65mm_EP1x1.6mm
U14: RT9526AGQW; DFN-8-1EP_3x2mm_P0.5mm_EP1.7x1.4mm

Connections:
+3V8: C16.1, C17.1, C18.2, C41.1, R5.2, R9.2, U2.4 (VOUT_4), U2.5 (VOUT_5), U13.6 (IN); also elsewhere on the board
BATT: J5.1, Q1.3 (D), U14.8 (BATT); also elsewhere on the board
EN: R18.1, U2.12 (EN); also elsewhere on the board
GND: C15.1, C16.2, C17.2, C18.1, C19.2, C20.2, C21.2, C22.2, C23.2, C28.2, C32.2, C40.2, C41.2, J5.2, R6.1, R12.2, R13.2, R14.2, R16.2, U2.2 (GND), U2.15 (PGND), U8.3 (VSS), U13.3 (GND), U13.7 (GND), U14.5 (GND), U14.9 (EP); also elsewhere on the board
unnamed: C22.1, C23.1, D4.1 (K), Q1.2 (S), R18.2, U2.10 (VIN_10), U2.11 (VIN_11)
unnamed: D6.2 (A), R19.2
unnamed: D6.1 (K), U14.3 (CHG_SB)
unnamed: D7.1 (K), R11.2, U8.1 (VOUT)
unnamed: Q1.1 (G), R17.2
unnamed: R5.1, R6.2, U2.3 (FB)
unnamed: L1.1, U2.8 (L1_8), U2.9 (L1_9)
unnamed: L1.2, U2.6 (L2_6), U2.7 (L2_7)
unnamed: C15.2, U2.1 (VINA), U2.13 (PS/SYNC)
unnamed: C28.1, U8.2 (CD)
unnamed: R9.1, U13.4 (EN)
unnamed: R14.1, U14.4 (ENB)
unnamed: R12.1, U14.6 (IMIN)
unnamed: R13.1, U14.7 (ISET)
PWRKEY: D7.2 (A); also elsewhere on the board
VUSB: C40.1, D4.2 (A), R16.1, R17.1, U14.1 (VIN); also elsewhere on the board

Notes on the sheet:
Vout = (R5/R6+1)*0.5
Imax=500mA
Note: BG95 auto power up circuit Hold low for 648ms before high after power up
3.796V
Note: no need pull-up resistor for XC6119C series need pull-up resistor for XC6119N series

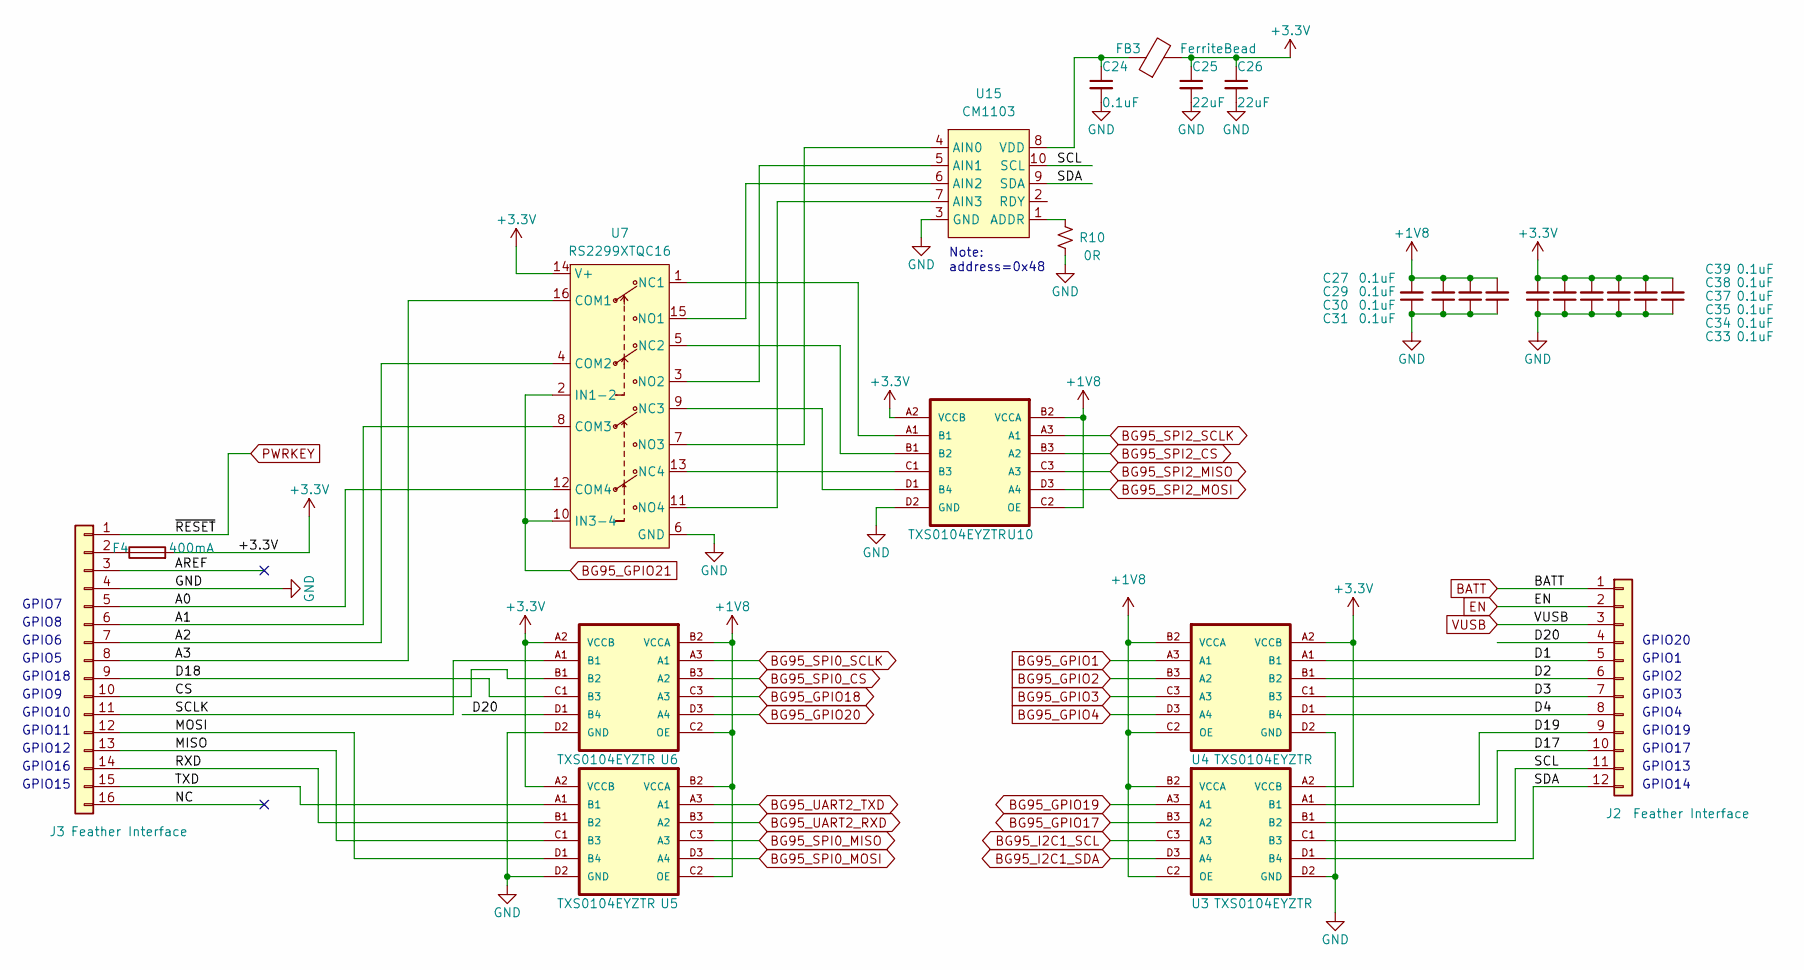
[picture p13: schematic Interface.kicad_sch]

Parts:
C24, C27, C29, C30, C31, C33, C34, C35, C37, C38, C39: 0.1uF; C_0402_1005Metric
C25, C26: 22uF; C_0402_1005Metric
F4: 400mA; Fuse_0603_1608Metric
FB3: FerriteBead; L_0402_1005Metric
J2: Feather Interface; PinHeader_1x12_P2.54mm_Vertical_SMD_Pin1Left
J3: Feather Interface; PinHeader_1x16_P2.54mm_Vertical_SMD_Pin1Right
R10: 0R; R_0201_0603Metric
U3, U4, U5, U6, U10: TXS0104EYZTR; BGA12N50P4X3_186X136X62N
U7: RS2299XTQC16; QFN-16-1EP_3x3mm_P0.5mm_EP1.75x1.75mm
U15: CM1103; CM1103-QFNTA

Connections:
+1V8: C27.2, C29.2, C30.2, C31.2, U3.B2 (VCCA), U3.C2 (OE), U4.B2 (VCCA), U4.C2 (OE), U5.B2 (VCCA), U5.C2 (OE), U6.B2 (VCCA), U6.C2 (OE), U10.B2 (VCCA), U10.C2 (OE); also elsewhere on the board
/Interface/A0: J3.5, U7.12 (COM4)
/Interface/A1: J3.6, U7.8 (COM3)
/Interface/A2: J3.7, U7.4 (COM2)
/Interface/A3: J3.8, U7.16 (COM1)
/Interface/AREF: J3.3
/Interface/CS: J3.10, U6.B1 (B2)
/Interface/D1: J2.5, U4.A1 (B1)
/Interface/D2: J2.6, U4.B1 (B2)
/Interface/D3: J2.7, U4.C1 (B3)
/Interface/D4: J2.8, U4.D1 (B4)
/Interface/D17: J2.10, U3.B1 (B2)
/Interface/D18: J3.9, U6.C1 (B3)
/Interface/D19: J2.9, U3.A1 (B1)
/Interface/D20: J2.4, U6.D1 (B4)
/Interface/MISO: J3.13, U5.C1 (B3)
/Interface/MOSI: J3.12, U5.D1 (B4)
/Interface/NC: J3.16
/Interface/RXD: J3.14, U5.B1 (B2)
/Interface/SCL: J2.11, U3.C1 (B3), U15.10 (SCL)
/Interface/SCLK: J3.11, U6.A1 (B1)
/Interface/SDA: J2.12, U3.D1 (B4), U15.9 (SDA)
/Interface/TXD: J3.15, U5.A1 (B1)
BATT: J2.1; also elsewhere on the board
BG95_GPIO1: U4.A3 (A1); also elsewhere on the board
BG95_GPIO2: U4.B3 (A2); also elsewhere on the board
BG95_GPIO3: U4.C3 (A3); also elsewhere on the board
BG95_GPIO4: U4.D3 (A4); also elsewhere on the board
BG95_GPIO17: U3.B3 (A2); also elsewhere on the board
BG95_GPIO18: U6.C3 (A3); also elsewhere on the board
BG95_GPIO19: U3.A3 (A1); also elsewhere on the board
BG95_GPIO20: U6.D3 (A4); also elsewhere on the board
BG95_GPIO21: U7.2 (IN1-2), U7.10 (IN3-4); also elsewhere on the board
BG95_I2C1_SCL: U3.C3 (A3); also elsewhere on the board
BG95_I2C1_SDA: U3.D3 (A4); also elsewhere on the board
BG95_SPI0_CS: U6.B3 (A2); also elsewhere on the board
BG95_SPI0_MISO: U5.C3 (A3); also elsewhere on the board
BG95_SPI0_MOSI: U5.D3 (A4); also elsewhere on the board
BG95_SPI0_SCLK: U6.A3 (A1); also elsewhere on the board
BG95_SPI2_CS: U10.B3 (A2); also elsewhere on the board
BG95_SPI2_MISO: U10.C3 (A3); also elsewhere on the board
BG95_SPI2_MOSI: U10.D3 (A4); also elsewhere on the board
BG95_SPI2_SCLK: U10.A3 (A1); also elsewhere on the board
BG95_UART2_RXD: U5.B3 (A2); also elsewhere on the board
BG95_UART2_TXD: U5.A3 (A1); also elsewhere on the board
EN: J2.2; also elsewhere on the board
GND: C24.2, C25.2, C26.2, C27.1, C29.1, C30.1, C31.1, C33.1, C34.1, C35.1, C37.1, C38.1, C39.1, J3.4, R10.2, U3.D2 (GND), U4.D2 (GND), U5.D2 (GND), U6.D2 (GND), U7.6 (GND), U10.D2 (GND), U15.3 (GND); also elsewhere on the board
unnamed: U7.1 (NC1), U10.A1 (B1)
unnamed: U7.5 (NC2), U10.B1 (B2)
unnamed: U7.13 (NC4), U10.C1 (B3)
unnamed: U7.9 (NC3), U10.D1 (B4)
unnamed: R10.1, U15.1 (ADDR)
unnamed: U7.7 (NO3), U15.4 (AIN0)
unnamed: U7.3 (NO2), U15.5 (AIN1)
unnamed: U7.15 (NO1), U15.6 (AIN2)
unnamed: U7.11 (NO4), U15.7 (AIN3)
unnamed: C24.1, FB3.1, U15.8 (VDD)
PWRKEY: J3.1; also elsewhere on the board
VUSB: J2.3; also elsewhere on the board

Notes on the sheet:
GPIO8
GPIO10
GPIO9
GPIO13
GPIO14
GPIO12
GPIO3
GPIO18
GPIO5
GPIO4
Note: address=0x48
GPIO6
GPIO20
GPIO17
GPIO15
GPIO16
GPIO2
GPIO19
GPIO1
GPIO7
GPIO11

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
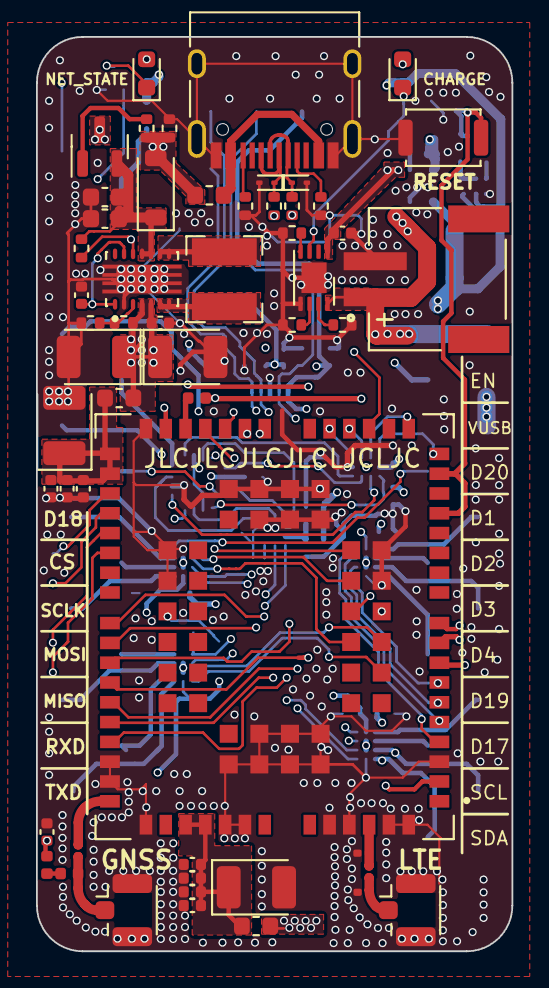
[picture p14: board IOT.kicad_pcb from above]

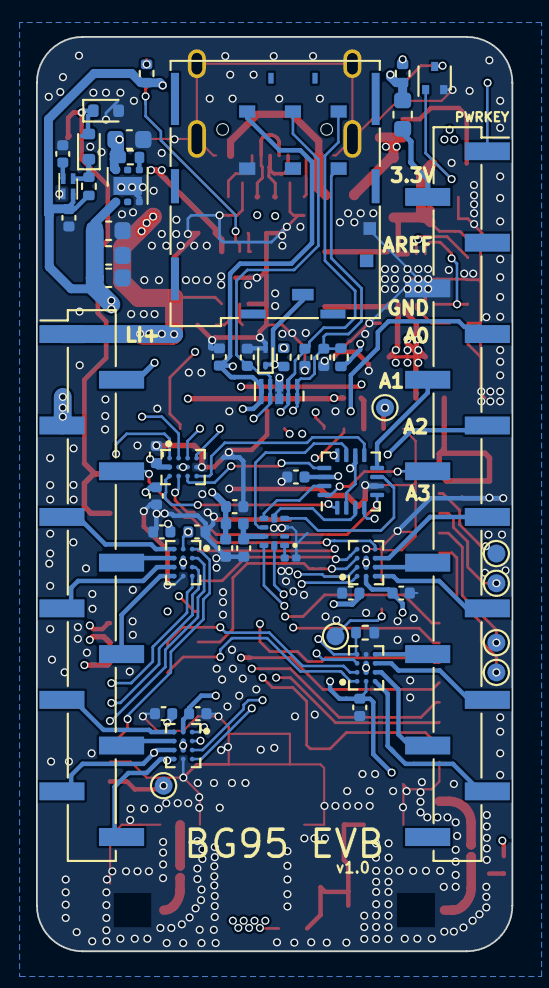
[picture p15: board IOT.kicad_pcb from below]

Board: 4 copper layers, 26.4 x 50.8 mm, 111 parts (57 on the bottom side), 104 nets.

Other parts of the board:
F3: 400mA; Fuse_0603_1608Metric

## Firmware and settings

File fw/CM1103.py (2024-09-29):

import log
from machine import Pin
from machine import I2C 
import utime as time

log.basicConfig(level=log.INFO)
i2c_log = log.getLogger("I2C")

ADDR_CM1103     =   0X48

REG_CONVERSION  =   0X00
REG_CONFIG      =   0X01
REG_THRESH_LO   =   0X02
REG_THRESH_HI   =   0X03


'''
note:The A0,A1,A2,A3 label on board didnot match the ADC chip's AINI0,AIN1,AIN2,AIN3 for batter layout
   | board label    |  CM1103 PIN
   |     A0         |      AIN3
   |     A1         |      AIN0
   |     A2         |      AIN1
   |     A3         |      AIN2
'''
A0  =  0
A1  =  1
A2  =  2
A3  =  3
mux_table = [0X07,0X04,0X05,0X06]

#first byte info in config register
BIT_OFFSET_OS   = 7
BIT_OFFSET_MUX  = 4
BIT_OFFSET_PGA  =   1
BIT_OFFSET_MODE =   0
#second byte info in config register
BIT_OFFSET_DR           =   5
BIT_OFFSET_COMP_MODE    =   4
BIT_OFFSET_POL          =   3
BIT_OFFSET_COMP_LAT     =   2
BIT_OFFSET_COMP_QUE     =   0

class OS:
    INVALID     = 0x00
    SINGLE_CONV = 0x01

class MUX:
    MUX_A0_A1   =   0x00
    MUX_A0_A3   =   0X01
    MUX_A1_A3   =   0X02
    MUX_A2_A3   =   0X03
    MUX_A0_GND  =   0X04
    MUX_A1_GND  =   0X05
    MUX_A2_GND  =   0X06
    MUX_A3_GND  =   0X07

class PGA:
    PGA_6144    =   0X00
    PGA_4096    =   0x01
    PGA_2048    =   0X02
    PGA_1024    =   0X03
    PGA_512     =   0X04
    PGA_256     =   0X05
    #PGA_256     =   0X06
    #PGA_256     =   0X07

class MODE:
    CONTINIOUS =   0X00
    SINGLE     =   0X01

class DR:
    DR_625  =   0X00
    DR_125  =   0X01
    DR_25   =   0X02
    DR_50   =   0X03
    DR_100  =   0X04
    DR_400  =   0X05
    DR_1000 =   0X06
    DR_2000 =   0X07

class COMP_MODE:
    NORMAL    =   0X00
    WINDOW    =   0X01

class COMP_POL:
    LOW        =   0X00
    HIGH       =   0X01

class COMP_LAT:
    ENABLE     =   0X01
    DISABLE    =   0X00

class COMP_QUE:
    SETUP1     =   0X00
    SETUP2     =   0X01
    SETUP4     =   0X02
    DISABLE    =   0X03

class CM1103():
    def __init__(self,i2c_obj):
        self._i2c = i2c_obj
        self._addr_reg_conversion = bytearray([REG_CONVERSION])
        self._addr_reg_config     = bytearray([REG_CONFIG])
        self._addr_reg_thresh_lo  = bytearray([REG_THRESH_LO])
        self._addr_reg_thresh_high= bytearray([REG_THRESH_HI])
        self._response = bytearray(2)

        self._convert           = None
        self._config            = None 
        self._lo_threshold      = None
        self._high_threshold    = None
        self._channel           = None

    @property
    def conversion(self):
        rsp = self._i2c.read(ADDR_CM1103,self._addr_reg_conversion,1,self._response,2,0) #reg address length is 1 and response datalength is 2 bytes
        if rsp==0:
            return self._response[0]*256+self._response[1]
        else:
            i2c_log.info("cm1103 read conversion register failed")
    
    @property
    def config(self):  # default value in this reg is :1000 0101 1000 0011
        rsp = self._i2c.read(ADDR_CM1103,self._addr_reg_config,1,self._response,2,0) #reg address length is 1 and response datalength is 2 bytes
        if rsp==0:
            self._config = self._response[0]*256+self._response[1] 
            return self._config
        else:
            i2c_log.error("cm1103 read config register failed")
           
    def write_config(self, os = OS.SINGLE_CONV, mux = MUX.MUX_A0_GND, pga = PGA.PGA_4096, mode = MODE.CONTINIOUS,
                     dr = DR.DR_100, comp_mode = COMP_MODE.WINDOW, comp_pol = COMP_POL.HIGH, comp_lat = COMP_LAT.DISABLE, comp_que = COMP_QUE.DISABLE):
        
        self._channel = mux #record the mux ad analogRead also need this info
        hsb = os<<BIT_OFFSET_OS|mux<<BIT_OFFSET_MUX|pga<<BIT_OFFSET_PGA|mode<<BIT_OFFSET_MODE
        lsb = dr<<BIT_OFFSET_DR|comp_mode<<BIT_OFFSET_COMP_MODE|comp_pol<<BIT_OFFSET_POL|comp_lat<<BIT_OFFSET_COMP_LAT|comp_que<<BIT_OFFSET_COMP_QUE
        config = bytearray([hsb,lsb])
        rsp = self._i2c.write(ADDR_CM1103,self._addr_reg_config,1,config,2)
        if rsp==0:
            return config
        else:
            i2c_log.error("cm1103 write config register failed")
            
    @property
    def lo_threshold(self):
        rsp = self._i2c.read(ADDR_CM1103,self._addr_reg_thresh_lo,1,self._response,2,0) #reg address length is 1 and response datalength is 2 bytes
        if rsp==0:
            return self._response[0]*256+self._response[1]

    @lo_threshold.setter
    def lo_threshold(self,val):
        pass 

    @property
    def high_threshold(self):
        rsp = self._i2c.read(ADDR_CM1103,self._addr_reg_thresh_high,1,self._response,2,0) #reg address length is 1 and response datalength is 2 bytes
        if rsp==0:
            return self._response[0]*256+self._response[1]
    
    @high_threshold.setter
    def high_threshold(self,val):
        pass
    
    #TODO,right now, this function only support single end ADC sample,A0,A1,A2,A3, which maps the physical feather board's pin map.
    def analogRead(self,ch):
        if ch<A0 and ch>A3:
            i2c_log.info("channel value is out of range, can only be between 0 and 3")
            return False
        if mux_table[ch]!= self._channel:
            self._channel = mux_table[ch]
            self.write_config(mux=self._channel)
        return self.conversion
    

if __name__=="__main__":

    #enable A0 to A3 
    analogSwitch = Pin(Pin.GPIO21,Pin.OUT,Pin.PULL_DISABLE,1)
    i2c_obj = I2C(I2C.I2C1, I2C.STANDARD_MODE)
    adc = CM1103(i2c_obj)
    adc.write_config(mode=MODE.CONTINIOUS,mux=MUX.MUX_A0_GND,pga=PGA.PGA_4096)
   
    retry =10
    while True:
        print(adc.analogRead(A3))
        time.sleep_ms(20)
        retry-=1
        if retry==0:
            break
    print("All done")  

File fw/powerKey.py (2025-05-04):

from misc import PowerKey
import utime

'''
pk = PowerKey()

def pwk_callback(status):
    if status == 0:
        print('powerkey release.------------')
    elif status == 1:
    	print('powerkey press.--------------')
    else :
        print("WTF-------------")



if __name__=="__main__":
    if pk.powerKeyEventRegister(pwk_callback)==0: # 只有按键释放时才会触发回调
        print("pwk register succeed")
    retry = 20
    while retry:
        if pk.powerKeyEventRegister(pwk_callback)==0: # 只有按键释放时才会触发回调
            print("pwk register succeed")
        retry-=1
        utime.sleep(0.5)
        print("Hello world")
'''

from misc import PowerKey
import osTimer

class Pwrkey(object):
    def __init__(self, time_threshold):   
        self.pk = PowerKey()
        self.time_threshold = time_threshold
        self.timer = osTimer()
        self.is_long_press = 0
        self.pk.powerKeyEventRegister(self.pwk_callback)

    def long_press_cb(self):
        print('powerkey long press.')

    def short_press_cb(self):
        print('powerkey short press.')        

    def pwk_timer_cb(self, arg): 
        self.is_long_press = 1

    def pwk_callback(self, status):
        if status == 0:
            print('powerkey release.')
            self.timer.stop()
            if self.is_long_press:
                self.long_press_cb()
            else:
                self.short_press_cb()

        elif status == 1:
            print('powerkey press.')
            self.is_long_press = 0
            self.timer.start(self.time_threshold, 0, self.pwk_timer_cb)


if __name__ == "__main__":

    
    retry=10
    while retry:
        pwrkey = Pwrkey(1000)
        retry-=1
        utime.sleep(1)

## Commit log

2024-09-16 initial commit for IoT_feather
    [BG95.kicad_sch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]
2024-09-29 reorganize the folder and add ADC driver in
    [BG95.kicad_sch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]
2025-05-04 update the quecpython project
    [BG95.kicad_sch, IOT.kicad_pcb, Power.kicad_sch]
